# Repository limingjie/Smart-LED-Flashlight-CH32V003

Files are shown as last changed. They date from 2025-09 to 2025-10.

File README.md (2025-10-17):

# Smart LED Flashlight - CH32V003

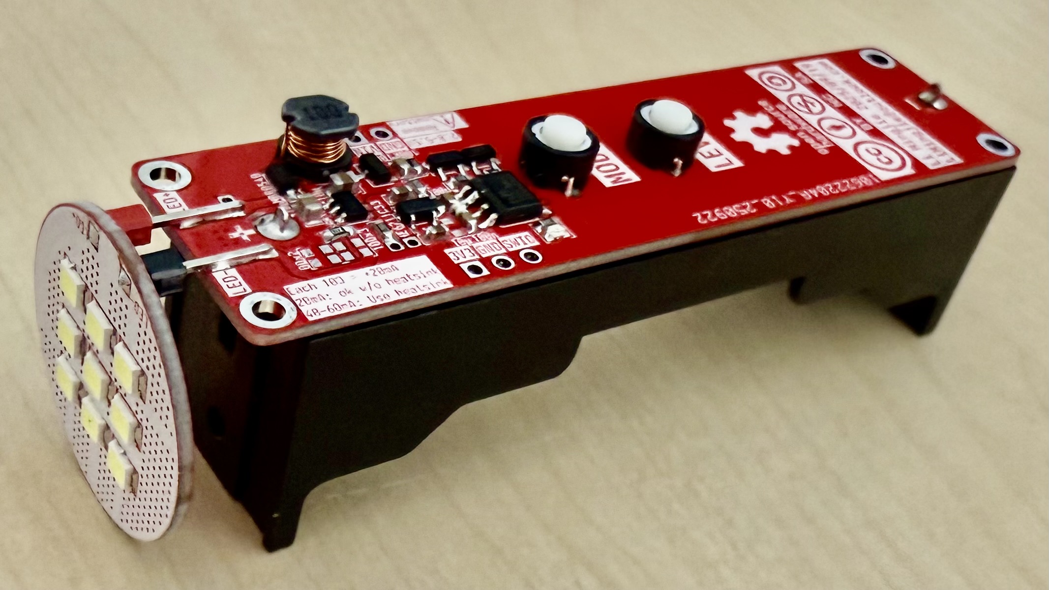
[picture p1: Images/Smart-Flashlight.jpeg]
Flashlight


**Smart LED Flashlight - CH32V003** is an open-source, compact, and energy-efficient flashlight solution based on the CH32V003 RISC-V microcontroller and SGM3732 LED driver.

It features multiple adjustable brightness lighting modes (Steady, Breathing, Blinking, SOS), battery monitoring, and zero standby current via a soft latching power circuit.

Designed for DIY enthusiasts, emergency kits, portable lighting, and educational projects.

- Low-cost, minimal component count
- USB or battery powered (3.0V–5.5V)
- Up to 10 LEDs in series
- Advanced features: PWM dimming, SOS mode, battery protection
- Open source hardware and firmware

---

- [Smart LED Flashlight - CH32V003](#smart-led-flashlight---ch32v003)
  - [Circuit on Breadboard](#circuit-on-breadboard)
  - [Schematic](#schematic)
  - [Features](#features)
  - [Components](#components)
    - [MCU - CH32V003](#mcu---ch32v003)
      - [Clock Selection](#clock-selection)
      - [Battery Monitoring](#battery-monitoring)
    - [LED Driver - SGM3732](#led-driver---sgm3732)
    - [Soft Latching Power Circuit](#soft-latching-power-circuit)
    - [LDO - ME6211](#ldo---me6211)
  - [Minimized ch32fun Library](#minimized-ch32fun-library)
  - [References](#references)
  - [License](#license)

## Circuit on Breadboard

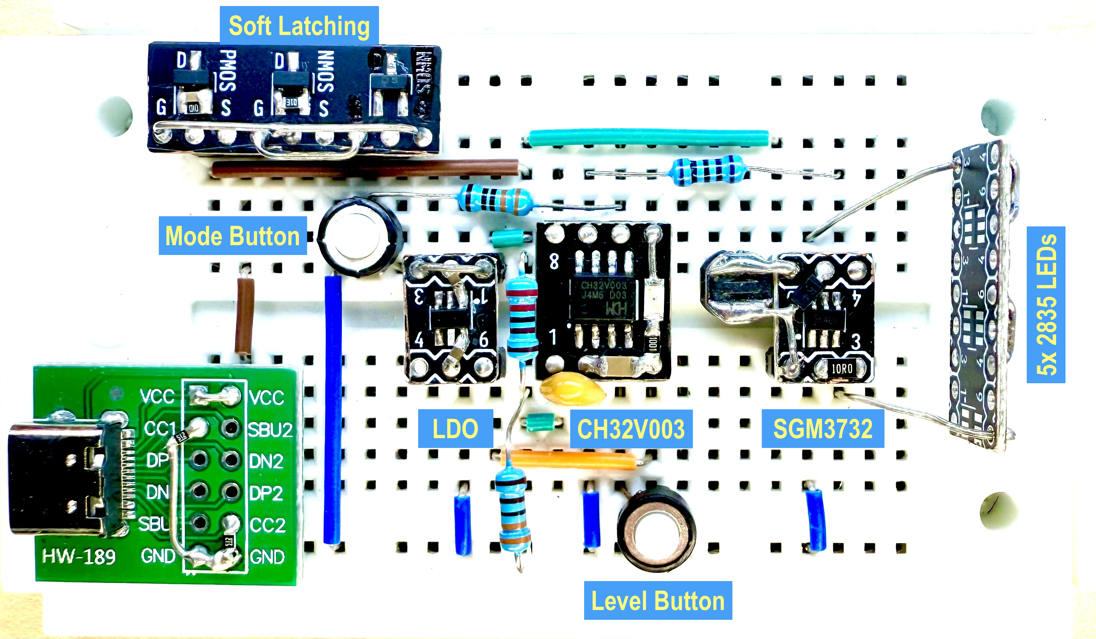
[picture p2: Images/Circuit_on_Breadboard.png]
Circuit on Breadboard


## Schematic

Schematic

## Features

- Low-cost
- PWM-controlled adjustable brightness
- Supports up to 10 LEDs in series
- Operates from `3.0V` to `5.5V` (suitable for single cell lithium battery)
- Soft latching power circuit for zero standby current
- Automatic power monitoring and low-voltage lockout to prevent battery drain
- 4 Modes - `Steady`, `Breathing`, `Blinking`, and `SOS`.
  - Click/Double click `Mode` button to switch to previous/next mode.
  - Hold `Mode` button anytime to directly switch to `SOS` mode.
- 8 Levels
  - Click/Double click `Level` button to increase/decrease.
  - Hold `Level` button to switch between min and max.

## Components

### MCU - CH32V003

The CH32V003 is a low-cost, high-performance 32-bit RISC-V microcontroller from WCH. It features a compact design, low power consumption, and a rich set of peripherals, making it ideal for embedded applications and cost-sensitive projects. The CH32V003 supports various interfaces such as UART, SPI, I2C, and PWM, and is well-suited for controlling LED drivers and other hardware components.

- [CH32V003 Datasheet V1.7](./Documents/CH32V003%20Datasheet%20-%20V1.7.PDF)
- [CH32V003 Reference Manual V1.7](./Documents/CH32V003%20Reference%20Manual%20-%20V1.7.PDF)

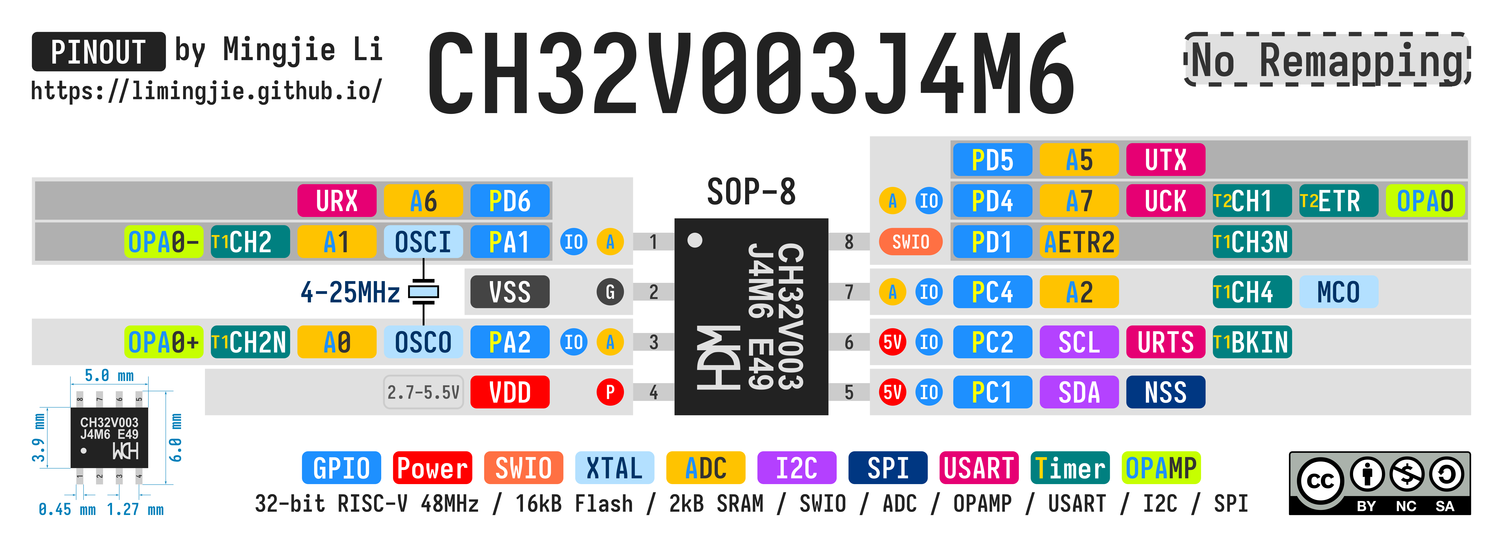
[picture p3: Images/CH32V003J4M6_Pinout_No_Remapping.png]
CH32V003 Pinout


[Link to More CH32V003 Pinout charts](https://github.com/limingjie/WCH-MCU-Pinouts/tree/main/MCU/CH32V)

#### Clock Selection

With a `1.5MHz` clock (`1/16` of the internal `24MHz` high-speed clock), the CH32V003 draws around `1.53mA` (the power LED draws around `1.35mA`). With clocks lower than `1.5MHz`, CH32V003 does not seem to work properly with ADC enabled and may brick the chip. If this happens, try the unbrick command (`minichlink -u`) or flash a firmware with a higher clock; note that it may require more than 10 attempts. The chip is quite robust, but recovering it may require patience!

#### Battery Monitoring

When using a lithium battery as the power supply, and considering the cutoff voltages of the CH32V003 and SGM3732, the lockout voltage is set at `3.0V` if detected 3 times.

- CH32V003: `2.8V`-`5.5V` (With ADC).
- SGM3732: `2.7V`-`5.5V`.

Since the power supply can drop below `3.3V`, directly using `3.3V` as the ADC reference would lead to inaccurate results. Fortunately, the CH32V003 provides an internal voltage reference (`1.2V` on analog channel 8), which allows for accurate ADC measurements with an error within `±1%`.

$$
\begin{align}
\text{V}_\text{Reference} &= \text{V}_\text{DD} \times \frac{\text{ADC}_{\text{Reference}}}{1023}
\Longrightarrow \text{V}_\text{DD} = \frac{\text{V}_\text{Reference}}{\frac{\text{ADC}_{\text{Reference}}}{1023}} \\
\text{V}_\text{Battery} &= \text{V}_\text{DD} \times \frac{\text{ADC}_{\text{Battery}}}{1023} \\
&= \frac{\text{V}_\text{Reference}}{\frac{\text{ADC}_{\text{Reference}}}{1023}} \times \frac{\text{ADC}_{\text{Battery}}}{1023} \\
&= \text{V}_\text{Reference} \times \frac{\text{ADC}_{\text{Battery}}}{\text{ADC}_\text{Reference}}\\
&=  1.2\ \text{V} \times \frac{\text{ADC}_{\text{Battery}}}{\text{ADC}_\text{Reference}}
\end{align}
$$

### LED Driver - SGM3732

The [SGM3732](https://www.sg-micro.com/product/SGM3732) is a high-efficiency constant current LED driver with a 1.1MHz PWM boost converter, optimized for compact designs using small components. It can drive up to 10 LEDs in series (up to 38V output) or deliver up to 260mA with 3 LEDs per string, while maintaining high conversion efficiency. LED current is programmable via a digital PWM dimming interface (2kHz–60kHz). The device features very low shutdown current and includes protections such as over-voltage, cycle-by-cycle input current limit, and thermal shutdown. The SGM3732 is available in a TSOT-23-6 package and operates from -40℃ to +85℃.

- [SGM3732 Datasheet Rev A4](./Documents/SGM3732%20Datasheet%20-%20Rev%20A4.pdf)
- [SGM3732 Datasheet Rev A3](./Documents/SGM3732%20Datasheet%20-%20Rev%20A3.pdf) – The older version includes circuit design and component selection guidance.

### Soft Latching Power Circuit

Refer to the [CH32V003 Soft Latching Power Circuits](https://github.com/limingjie/CH32V003-Soft-Latching-Power-Circuits) project.

### LDO - ME6211

The CH32V003 operates from `2.7V` to `5.5V`, but shows noticeable current fluctuations when powered directly from USB. Using an LDO stabilizes the MCU’s power supply and reduces current consumption by a few milliamps.

When the input voltage drops under `3.3V`, LDO stops regulate, the output voltage is $\text{V}_\text{In} - \text{V}_\text{Dropout}$. The dropout voltage is `~2.6mV` ($\text{V}_\text{In}$ = `~3.3V`) to `5mV` ($\text{V}_\text{In}$ = `2.85V`) when the power consumption is `~3mA`.

- [ME6211 Datasheet - V24](./Documents/ME6211%20Datasheet%20-%20V26.pdf)

## Minimized ch32fun Library

- **`ch32fun.mk`** - Some modifications to accommodate library and tool paths.
  - The `LDFLAGS` path change is for locating the `ch32fun/libgcc.a`.

    ```diff
    <     LDFLAGS+=-L$(CH32FUN)/../misc -lgcc
    ---
    >     LDFLAGS+=-L$(CH32FUN) -lgcc
    ```

    - Otherwise, the compiler would use the default libgcc and throw an incompatible linking error:

      ```text
      .../riscv64-unknown-elf/bin/ld:
      .../riscv-gnu-toolchain/main/lib/gcc/riscv64-unknown-elf/15.1.0/libgcc.a(div.o):
      ABI is incompatible with that of the selected emulation:
      target emulation `elf64-littleriscv' does not match `elf32-littleriscv'
      ```

  - The other two changes are for `minichlink`:

    ```diff
    33c33
    < MINICHLINK?=$(CH32FUN)/../minichlink
    ---
    > MINICHLINK?=$(CH32FUN)
    51c51
    <     LDFLAGS+=-L$(CH32FUN)/../misc -lgcc
    ---
    >     LDFLAGS+=-L$(CH32FUN) -lgcc
    350c350
    <     make -C $(MINICHLINK) all
    ---
    >     # make -C $(MINICHLINK) all
    ```

- **`ch32fun.c`**
  - Changed line `1728` for `6MHz` HCLK, resulting in lower power consumption (<`2.6mA`).

    ```c
    1720: #elif defined(FUNCONF_USE_HSI) && FUNCONF_USE_HSI
    1721: #if defined(CH32V30x) || defined(CH32V20x) || defined(CH32V10x)
    1722:     EXTEN->EXTEN_CTR |= EXTEN_PLL_HSI_PRE;
    1723: #endif
    1724: #if defined(FUNCONF_USE_PLL) && FUNCONF_USE_PLL
    1725:     RCC->CFGR0 = BASE_CFGR0;
    1726:     RCC->CTLR  = BASE_CTLR | RCC_HSION | RCC_PLLON; // Use HSI, enable PLL.
    1727: #else
    1728:     RCC->CFGR0 = RCC_HPRE_DIV4;                    // HCLK = SYSCLK / 4
    1729:     RCC->CTLR  = BASE_CTLR | RCC_HSION;             // Use HSI only.
    1730: #endif
    ```

  - Set ADC sampling time to `241` cycles for better accuracy.

    ```c
    1808: // set sampling time for all channels to 0b111 (241 cycles).
    1809: ADC1->SAMPTR2 = (ADC_SMP0<<(3*0)) | (ADC_SMP0<<(3*1)) | (ADC_SMP0<<(3*2)) | (ADC_SMP0<<(3*3)) | (ADC_SMP0<<  (3*4)) | (ADC_SMP0<<(3*5)) | (ADC_SMP0<<(3*6)) | (ADC_SMP0<<(3*7)) | (ADC_SMP0<<(3*8)) | (ADC_SMP0<<(3*9));
    1810: ADC1->SAMPTR1 = (ADC_SMP0<<(3*0)) | (ADC_SMP0<<(3*1)) | (ADC_SMP0<<(3*2)) | (ADC_SMP0<<(3*3)) | (ADC_SMP0<<  (3*4)) | (ADC_SMP0<<(3*5));
    ```

## References

- [Andrew Levido: Soft Latching Power Circuits](https://circuitcellar.com/resources/quickbits/soft-latching-power-circuits/)
- [CNLohr: ch32fun](https://github.com/cnlohr/ch32fun)
- [A Guide to Debouncing](https://my.eng.utah.edu/~cs5780/debouncing.pdf)
- [The simplest button debounce solution](https://www.e-tinkers.com/2021/05/the-simplest-button-debounce-solution/)
- [Museum of the Game - Let's design some POKEY replacements](https://forums.arcade-museum.com/threads/lets-design-some-pokey-replacements.515774/post-4623716)

## License

CC by-nc-sa

This work is licensed under a [Creative Commons Attribution-NonCommercial-ShareAlike 4.0 International License (CC BY-NC-SA 4.0)](https://creativecommons.org/licenses/by-nc-sa/4.0/).

**You are free to:**

- **Share** — copy and redistribute the material in any medium or format
- **Adapt** — remix, transform, and build upon the material

The licensor cannot revoke these freedoms as long as you follow the license terms.

**Under the following terms:**

- **Attribution** - You must give appropriate credit, provide a link to the license, and indicate if changes were made. You may do so in any reasonable manner, but not in any way that suggests the licensor endorses you or your use.
- **NonCommercial** - You may not use the material for commercial purposes.
- **ShareAlike** - If you remix, transform, or build upon the material, you must distribute your contributions under the same license as the original.
- **No additional restrictions** — You may not apply legal terms or technological measures that legally restrict others from doing anything the license permits.

**Notices:**

You do not have to comply with the license for elements of the material in the public domain or where your use is permitted by an applicable exception or limitation.

No warranties are given. The license may not give you all of the permissions necessary for your intended use. For example, other rights such as publicity, privacy, or moral rights may limit how you use the material.

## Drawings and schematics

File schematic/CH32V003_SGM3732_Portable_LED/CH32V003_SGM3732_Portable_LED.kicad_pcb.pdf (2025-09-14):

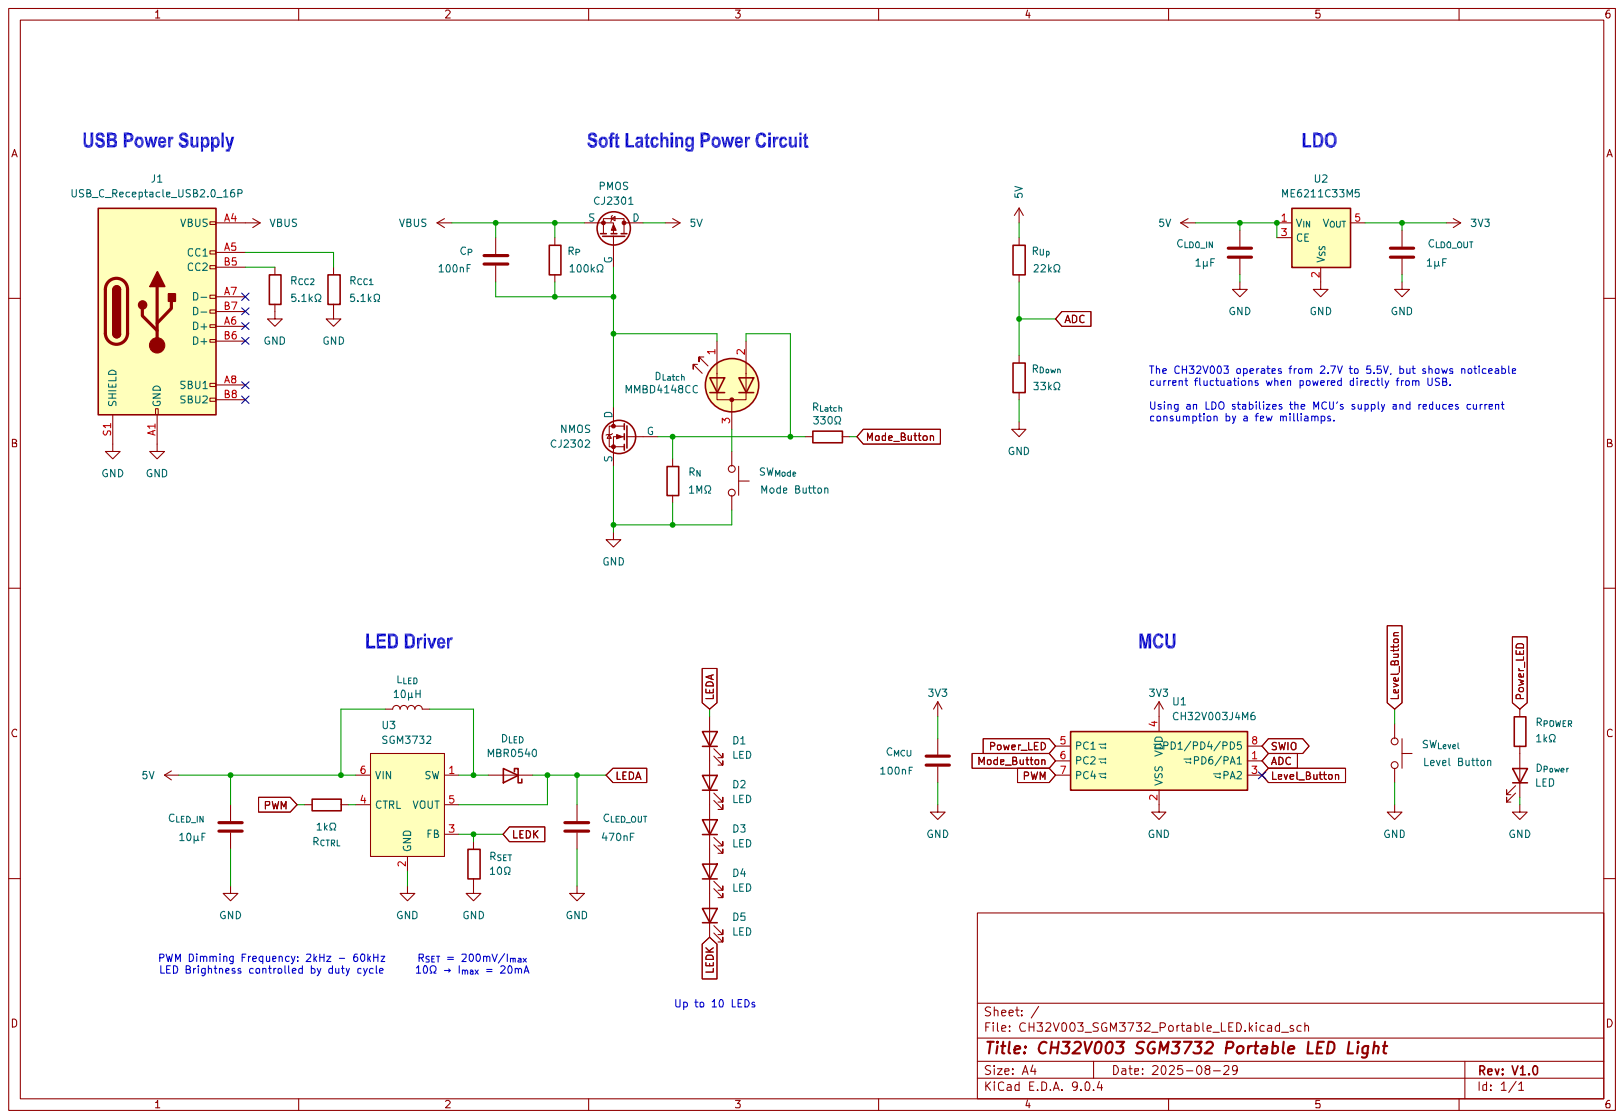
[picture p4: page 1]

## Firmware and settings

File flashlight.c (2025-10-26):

/*
 * Smart LED Flashlight - CH32V003
 *
 * Aug 2025 by Li Mingjie
 *  - Email:  limingjie@outlook.com
 *  - GitHub: https://github.com/limingjie/
 */

#include <stdio.h>
#include <stdlib.h>
#include "ch32fun.h"
#include "button.h"

#define PIN_POWER_LED     PC1       // Power LED pin
#define PIN_LATCH         PC2       // Latch pin
#define PIN_MODE_BUTTON   PC2       // Mode button pin, same as latch pin
#define PIN_LEVEL_BUTTON  PA2       // Set button pin
#define PIN_PWM           PC4       // PWM output pin
#define PIN_POWER_MONITOR PD6       // Power monitoring pin
#define ADC_POWER_MONITOR ANALOG_6  // Power monitoring ADC channel A6 (PD6)

#define POWER_MONITORING_CYCLES     1000  // Every 5 seconds - button_debounce() = 5ms
#define POWER_VOLT_DIV_R_UP         2     // 22k or 10k   | 2:3 voltage divider
#define POWER_VOLT_DIV_R_DOWN       3     // 33k or 15k   | 5.5V / 5 x 3 = 3.3V
#define POWER_LOW_VOLT_THRESHOLD_MV 3000  // 3.0V
#define POWER_LOW_COUNT_THRESHOLD   3     // 3 times

#define PWM_FREQUENCY              ((uint32_t)60 * 1000)                        // 60kHz
#define PWM_CLOCKS_FULL_DUTY_CYCLE (FUNCONF_SYSTEM_CORE_CLOCK / PWM_FREQUENCY)  // 100% duty cycle
#define PWM_CLOCKS_ZERO_DUTY_CYCLE 0                                            // 0% duty cycle
#define PWM_SEQUENCE_ON            1
#define PWM_SEQUENCE_OFF           0
#define PWM_SEQUENCE_INCREASE      1
#define PWM_SEQUENCE_DECREASE      0

#define MORSE_CODE_DIT_DURATION_MS 150  // 100ms

// #define printf(...) (void)0  // Disable printf to save flash

enum light_modes
{
    MODE_STEADY,
    MODE_BREATHING,
    MODE_BLINKING,
    MODE_SOS,
    MODE_OFF
};

const char* mode_names[] = {"MODE_STEADY", "MODE_BREATHING", "MODE_BLINKING", "MODE_SOS"};

uint8_t  current_mode           = 0;     // 5 modes: brightness, blink, dimming, sos, off
uint8_t  current_level          = 0;     // 0-7 levels of brightness, blink speed, dimming speed.
uint16_t current_pwm_duty_cycle = 0;     // Lights off
uint32_t pwm_update_interval_ms = 1000;  // systick interval in ms, set before initialize systick.
uint8_t  pwm_sequence           = 0;     // 0 - off / decrease; 1 - on / increase; 0-31 - sos sequence

void systick_init(void)
{
    SysTick->CTLR = 0;
    NVIC_EnableIRQ(SysTicK_IRQn);
    SysTick->CMP  = FUNCONF_SYSTEM_CORE_CLOCK / 1000 * pwm_update_interval_ms;
    SysTick->CNT  = 0;
    SysTick->CTLR = SYSTICK_CTLR_STE | SYSTICK_CTLR_STIE | SYSTICK_CTLR_STCLK;
}

// Gamma brightness lookup table <https://victornpb.github.io/gamma-table-generator>
// gamma = 2.00 steps = 100 range = 0-1023
const uint16_t gamma_lookup_table[100] = {
    0,   0,   0,   1,   2,   3,   4,   5,   7,   8,   10,  13,  15,  18,  20,  23,  27,  30,  34,   38,
    42,  46,  51,  55,  60,  65,  71,  76,  82,  88,  94,  100, 107, 114, 121, 128, 135, 143, 151,  159,
    167, 175, 184, 193, 202, 211, 221, 231, 240, 251, 261, 271, 282, 293, 304, 316, 327, 339, 351,  363,
    376, 388, 401, 414, 428, 441, 455, 469, 483, 497, 511, 526, 541, 556, 572, 587, 603, 619, 635,  651,
    668, 685, 702, 719, 736, 754, 772, 790, 808, 827, 845, 864, 883, 903, 922, 942, 962, 982, 1002, 1023,
};

void disable_systick(void)
{
    NVIC_DisableIRQ(SysTicK_IRQn);
}

void SysTick_Handler(void) __attribute__((interrupt));
void SysTick_Handler(void)
{
    SysTick->CMP += FUNCONF_SYSTEM_CORE_CLOCK / 1000 * pwm_update_interval_ms;
    SysTick->SR = 0;

    // process mode and level changes
    switch (current_mode)
    {
        case MODE_BREATHING:
            TIM1->CH4CVR = PWM_CLOCKS_FULL_DUTY_CYCLE * gamma_lookup_table[current_pwm_duty_cycle] / 1023;
            (pwm_sequence == PWM_SEQUENCE_INCREASE) ? current_pwm_duty_cycle++ : current_pwm_duty_cycle--;
            if (current_pwm_duty_cycle >= 100 || current_pwm_duty_cycle <= 0)
            {
                pwm_sequence = !pwm_sequence;
            }
            break;
        case MODE_BLINKING:
            TIM1->CH4CVR = (pwm_sequence == PWM_SEQUENCE_ON) ? PWM_CLOCKS_FULL_DUTY_CYCLE : PWM_CLOCKS_ZERO_DUTY_CYCLE;
            pwm_sequence = !pwm_sequence;
            break;
        case MODE_SOS:
            // From Wikipedia:
            // > The duration of a dah is three times the duration of a dit. Each dit or dah within an encoded character
            // > is followed by a period of signal absence, called a space, equal to the dit duration.
            // SOS Morse Code is the following sequence under a fixed systick.
            //   Morse Code - . . . --- --- --- . . . <-Wait->  | SOS   Time   = 0.15s x 24 = 3.6s
            //       Binary - 10101011101110111010101000000000  | Pause Time   = 0.15s x  8 = 1.2s
            //                |----+----|----+----|----+----|-  | Total Time   = 0.15s x 32 = 4.8s
            //     Sequence - 0    5   10   15   20   25   30   | No. Sequence = 32
            //           On - 0 2 4 678 012 456 8 0 2           | On  Sequence = 15
            //          Off -  1 3 5   9   3   7 9 1 345678901  | Off Sequence = 17
            TIM1->CH4CVR = (pwm_sequence >= 23 ||
                            ((pwm_sequence & 0x1) && pwm_sequence != 7 && pwm_sequence != 11 && pwm_sequence != 15))
                               ? PWM_CLOCKS_ZERO_DUTY_CYCLE
                               : PWM_CLOCKS_FULL_DUTY_CYCLE;

            pwm_update_interval_ms = MORSE_CODE_DIT_DURATION_MS;

            pwm_sequence++;
            pwm_sequence &= 0x1F;  // pwm_sequence %= 32;
            break;
    }
}

void tim1_pwm_init(void)
{
    // Enable GPIOC and TIM1
    RCC->APB2PCENR |= RCC_APB2Periph_GPIOC | RCC_APB2Periph_TIM1;

    // PC4 is T1CH4, 10MHz Output alt func, push-pull
    GPIOC->CFGLR &= ~(0xf << (4 * 4));
    GPIOC->CFGLR |= (GPIO_Speed_10MHz | GPIO_CNF_OUT_PP_AF) << (4 * 4);

    // Reset TIM1 to init all regs
    RCC->APB2PRSTR |= RCC_APB2Periph_TIM1;
    RCC->APB2PRSTR &= ~RCC_APB2Periph_TIM1;

    // Prescaler
    TIM1->PSC = 0x0000;

    // Auto Reload - sets period
    TIM1->ATRLR = PWM_CLOCKS_FULL_DUTY_CYCLE - 1;

    // Reload immediately
    TIM1->SWEVGR |= TIM_UG;

    // Enable CH4 output, positive pol
    TIM1->CCER |= TIM_CC4E | TIM_CC4NP;

    // CH2 Mode is output, PWM1 (CC1S = 00, OC1M = 110)
    TIM1->CHCTLR2 |= TIM_OC4M_2 | TIM_OC4M_1;

    // Set the Capture Compare Register value to 0% initially
    TIM1->CH4CVR = PWM_CLOCKS_ZERO_DUTY_CYCLE;

    // Enable TIM1 outputs
    TIM1->BDTR |= TIM_MOE;

    // Enable TIM1
    TIM1->CTLR1 |= TIM_CEN;
}

void blink_power_led(uint8_t times)
{
    for (uint8_t i = 0; i < times; i++)
    {
        funDigitalWrite(PIN_POWER_LED, FUN_HIGH);  // Turn on LED
        Delay_Ms(100);
        funDigitalWrite(PIN_POWER_LED, FUN_LOW);  // Turn off LED
        Delay_Ms(100);
    }
}

void power_monitor(void)
{
    static uint8_t power_low_count = 0;
    uint16_t       adc_ref         = 0;  // Internal reference 1.2V
    uint16_t       adc_mon         = 0;
    uint32_t       adc_volt_mv;
    uint32_t       power_volt_mv;

    // Average 8 samples for better stability
    for (uint8_t i = 0; i < 8; i++)
    {
        adc_ref += funAnalogRead(ANALOG_8);           // Internal reference 1.2V
        adc_mon += funAnalogRead(ADC_POWER_MONITOR);  // A6 (PD6)
    }
    adc_ref /= 8;
    adc_mon /= 8;

    adc_volt_mv   = (uint32_t)adc_mon * 1200 / adc_ref;
    power_volt_mv = adc_volt_mv * (POWER_VOLT_DIV_R_UP + POWER_VOLT_DIV_R_DOWN) / POWER_VOLT_DIV_R_DOWN;

    printf("Vref: 1.2 V (%d) | Vadc: %ld mV (%d) | Vpower: %ld mV\n", adc_ref, adc_volt_mv, adc_mon, power_volt_mv);

    if (power_volt_mv < POWER_LOW_VOLT_THRESHOLD_MV)
    {
        if (++power_low_count >= POWER_LOW_COUNT_THRESHOLD)
        {
            printf("Battery too low! Powering off...\n");
            blink_power_led(10);
            funDigitalWrite(PIN_LATCH, FUN_LOW);  // Input pull-down
            // For debugging purpose only, code should not reach here if correctly shutdown.
            power_low_count = 0;
        }
    }
    else
    {
        power_low_count = 0;
    }
}

void update_led(void)
{
    printf("Change to %s, level %d\n", mode_names[current_mode], current_level);

    disable_systick();

    switch (current_mode)
    {
        case MODE_STEADY:
            TIM1->CH4CVR = (PWM_CLOCKS_FULL_DUTY_CYCLE * (8 - current_level)) >> 3;  // 12.5, 25%, 37.5%, ..., 100%
            break;
        case MODE_BREATHING:
            pwm_sequence           = PWM_SEQUENCE_DECREASE;     // Starts by decreasing brightness
            pwm_update_interval_ms = (current_level + 1) << 1;  // 2ms, 4ms, 6ms, ..., 16ms
            current_pwm_duty_cycle = 100;                       // 100% duty cycle
            systick_init();
            break;
        case MODE_BLINKING:
            pwm_sequence           = PWM_SEQUENCE_ON;
            pwm_update_interval_ms = (current_level + 3) << 5;  // 96ms, 128ms, 160ms, ..., 320ms
            systick_init();
            break;
        case MODE_SOS:
            pwm_sequence           = 0;                           // Reset sequence
            TIM1->CH4CVR           = PWM_CLOCKS_ZERO_DUTY_CYCLE;  // Pause before SOS
            pwm_update_interval_ms = MORSE_CODE_DIT_DURATION_MS;
            systick_init();
            break;
        case MODE_OFF:
            TIM1->CH4CVR = PWM_CLOCKS_ZERO_DUTY_CYCLE;
            break;
    }
}

int main(void)
{
    SystemInit();
    Delay_Ms(50);

    funGpioInitAll();

    // Power on latch by input pull-up
    funPinMode(PIN_LATCH, GPIO_CFGLR_IN_PUPD);
    funDigitalWrite(PIN_LATCH, FUN_HIGH);

    // Init LED pin
    funPinMode(PIN_POWER_LED, GPIO_Speed_10MHz | GPIO_CNF_OUT_PP);
    funDigitalWrite(PIN_POWER_LED, FUN_HIGH);

    // Init ADC for battery voltage monitoring
    funAnalogInit();
    funPinMode(PIN_POWER_MONITOR, GPIO_CFGLR_IN_ANALOG);

    // Init TIM1 for PWM
    tim1_pwm_init();
    // TIM1->CH4CVR = PWM_CLOCKS_FULL_DUTY_CYCLE;  // Starts with MODE_STEADY - 100% brightness
    update_led();

    button_t mode_button;
    init_button(&mode_button, PIN_MODE_BUTTON);
    button_t level_button;
    init_button(&level_button, PIN_LEVEL_BUTTON);

    uint16_t power_monitoring_cycles = 0;
    while (1)
    {
        switch (get_button_event(&mode_button))
        {
            case BUTTON_HOLD:  // Enter SOS mode directly
                if (current_mode != MODE_SOS)
                {
                    current_mode = MODE_SOS;
                    update_led();
                }
                break;
            case BUTTON_RELEASED:  // Light mode +
                // printf("Mode button released.\n");
                // Move to next mode
                current_mode++;
                if (current_mode == MODE_OFF)
                {
                    // printf("Powering off...\n");
                    funDigitalWrite(PIN_LATCH, FUN_LOW);  // Input pull-down

                    // These following lines are for debugging purpose only, code should not reach here if correctly
                    // shutdown. However, if the MCU is powered by WCH-LinkE, the code will keep running. And, the
                    // button processing logic would detect the power off pull down as a button down, then there would
                    // be endless BUTTON_HOLD events.
                    Delay_Ms(100);
                    funDigitalWrite(PIN_LATCH, FUN_HIGH);  // Input pull-up
                    current_mode  = MODE_STEADY;
                    current_level = 0;
                    update_led();
                    break;
                }

                current_level = 0;  // Reset level to max
                update_led();
                break;
            case BUTTON_DOUBLE_PRESS_RELEASED:  // Light mode -
            case BUTTON_TRIPLE_PRESS_RELEASED:
            case BUTTON_MORE_PRESS_RELEASED:
                if (current_mode > MODE_STEADY)
                {
                    current_mode--;
                    current_level = 0;  // Reset level to max
                    update_led();
                }
                break;
        }

        switch (get_button_event(&level_button))
        {
            case BUTTON_RELEASED:  // Light level +
                // printf("Set button released.\n");
                if (current_mode != MODE_SOS)  // Do not interfere with SOS mode
                {
                    current_level++;
                    current_level %= 8;  // 0 - 7
                    update_led();
                }
                break;
            case BUTTON_DOUBLE_PRESS_RELEASED:  // Light level -
            case BUTTON_TRIPLE_PRESS_RELEASED:
            case BUTTON_MORE_PRESS_RELEASED:
                // printf("Set button double press released.\n");
                if (current_mode != MODE_SOS)  // Do not interfere with SOS mode
                {
                    if (current_level > 0)
                    {
                        current_level--;
                    }
                    else
                    {
                        current_level = 7;
                    }
                    update_led();
                }
                break;
            case BUTTON_HOLD:  // Change light level to min or max
                // printf("Set button hold.\n");
                if (current_mode != MODE_SOS)  // Do not interfere with SOS mode
                {
                    current_level = (current_level & 0x4) ? 0 : 7;  // 0/1/2/3 -> 7; 4/5/6/7 -> 0
                    update_led();
                }
                break;
        }

        if (current_mode != MODE_SOS)  // In an SOS, do not check power to avoid interference
        {
            if (++power_monitoring_cycles >= POWER_MONITORING_CYCLES)
            {
                power_monitor();
                power_monitoring_cycles = 0;
            }
        }

        debounce_delay();
    }
}

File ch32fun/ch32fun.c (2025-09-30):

// Mixture of embedlibc, and ch32v00x_startup.c
// Use with newlib headers.
// Mixture of weblibc, mini-printf and ???
/* This file contains the following functions:

// libc (via musl) mixture and miniprintf

int printf( const char* format, ... )
int vprintf(const char* format, va_list args)
int snprintf( char * buffer, unsigned int buffer_len, const char* format, ... )
int sprintf( char * buffer, const char * format, ... )
size_t wcrtomb(char *restrict s, wchar_t wc, mbstate_t *restrict st)
int wctomb(char *s, wchar_t wc)
size_t strlen(const char *s)
size_t strnlen(const char *s, size_t n)
void *memset(void *dest, int c, size_t n)
char *strcpy(char *d, const char *s)
char *strncpy(char *d, const char *s, size_t n)
int strcmp(const char *l, const char *r)
int strncmp(const char *_l, const char *_r, size_t n)
static char *twobyte_strstr(const unsigned char *h, const unsigned char *n)
static char *threebyte_strstr(const unsigned char *h, const unsigned char *n)
static char *fourbyte_strstr(const unsigned char *h, const unsigned char *n)
static char *twoway_strstr(const unsigned char *h, const unsigned char *n)
char *strstr(const char *h, const char *n)
char *strchr(const char *s, int c)
void *__memrchr(const void *m, int c, size_t n)
char *strrchr(const char *s, int c)
void *memcpy(void *dest, const void *src, size_t n)
int memcmp(const void *vl, const void *vr, size_t n)
void *memmove(void *dest, const void *src, size_t n)
void *memchr(const void *src, int c, size_t n)
int puts(const char *s)
int mini_itoa(long value, unsigned int radix, int uppercase, int unsig,
	 char *buffer)
int mini_vsnprintf(char *buffer, unsigned int buffer_len, const char *fmt, va_list va)
int mini_vpprintf(int (*puts)(char* s, int len, void* buf), void* buf, const char *fmt, va_list va)
int mini_snprintf(char* buffer, unsigned int buffer_len, const char *fmt, ...)
int mini_pprintf(int (*puts)(char*s, int len, void* buf), void* buf, const char *fmt, ...)

// IRQ Handling Code
void DefaultIRQHandler( void )
void NMI_RCC_CSS_IRQHandler( void )

// Startup Code
void InterruptVectorDefault( void )
void handle_reset( void )

// Configuration-specific I/O

#if defined( FUNCONF_USE_UARTPRINTF ) && FUNCONF_USE_UARTPRINTF
void SetupUART( int uartBRR )
int _write(int fd, const char *buf, int size)
int putchar(int c)
#endif

#if defined( FUNCONF_USE_DEBUGPRINTF ) && FUNCONF_USE_DEBUGPRINTF
void handle_debug_input( int numbytes, uint8_t * data ) // You can override this!
void poll_input( void )
int _write(int fd, const char *buf, int size)
int putchar(int c)
void SetupDebugPrintf( void )
void WaitForDebuggerToAttach()
#endif

#if (defined( FUNCONF_USE_DEBUGPRINTF ) && !FUNCONF_USE_DEBUGPRINTF) && \
	(defined( FUNCONF_USE_UARTPRINTF ) && !FUNCONF_USE_UARTPRINTF) && \
	(defined( FUNCONF_NULL_PRINTF ) && FUNCONF_NULL_PRINTF)

int _write(int fd, const char *buf, int size)
int putchar(int c)
#endif

void DelaySysTick( uint32_t n )
void SystemInit( void )

#ifdef CPLUSPLUS
extern void __cxa_pure_virtual()
void __libc_init_array(void)
#endif

*/

// We pre-define these, because if the user is (for some awful reason) using gcc-riscv64-linux-gnu with newlib, it will fail to compile if it janks up the stdio/string functions.
#define _SSP_STRING_H_
#define _SSP_STDIO_H_

#include <stdio.h>
#include <string.h>
#include <stdarg.h>
#include <limits.h>
#include <stdint.h>
#include <ch32fun.h>

#define WEAK __attribute__((weak))

WEAK int errno;

static int __puts_uart( char *s, int len, void *buf )
{
	(void)buf;

	_write( 0, s, len );
	return len;
}

WEAK int printf( const char* format, ... )
{
	va_list args;
	va_start( args, format );
	int ret_status = mini_vpprintf(__puts_uart, 0, format, args);
	va_end( args );
	return ret_status;
}

WEAK int vprintf(const char* format, va_list args)
{
	return mini_vpprintf(__puts_uart, 0, format, args);
}

WEAK int snprintf( char * buffer, unsigned int buffer_len, const char* format, ... )
{
	va_list args;
	va_start( args, format );
	int ret = mini_vsnprintf( buffer, buffer_len, format, args );
	va_end( args );
	return ret;
}

WEAK int sprintf( char * buffer, const char * format, ... )
{
	va_list args;
	va_start( args, format );
	int ret = mini_vsnprintf( buffer, INT_MAX, format, args );
	va_end( args );
	return ret;
}

/* Some stuff from MUSL


----------------------------------------------------------------------
Copyright © 2005-2020 Rich Felker, et al.

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
THE SOFTWARE IS PROVIDED "AS IS", WITHOUT WARRANTY OF ANY KIND,
EXPRESS OR IMPLIED, INCLUDING BUT NOT LIMITED TO THE WARRANTIES OF
MERCHANTABILITY, FITNESS FOR A PARTICULAR PURPOSE AND NONINFRINGEMENT.
IN NO EVENT SHALL THE AUTHORS OR COPYRIGHT HOLDERS BE LIABLE FOR ANY
CLAIM, DAMAGES OR OTHER LIABILITY, WHETHER IN AN ACTION OF CONTRACT,
TORT OR OTHERWISE, ARISING FROM, OUT OF OR IN CONNECTION WITH THE
SOFTWARE OR THE USE OR OTHER DEALINGS IN THE SOFTWARE.
----------------------------------------------------------------------

*/

/*
 * mbstate_t is an opaque object to keep conversion state, during multibyte
 * stream conversions.  The content must not be referenced by user programs.
 */

#define CURRENT_UTF8 0
#define IS_CODEUNIT(c) ((unsigned)(c)-0xdf80 < 0x80)
#define MB_CUR_MAX (CURRENT_UTF8 ? 4 : 1)

typedef void * mbstate_t;

#ifdef UNICODE
WEAK size_t wcrtomb(char *restrict s, wchar_t wc, mbstate_t *restrict st)
{
	if (!s) return 1;
	if ((unsigned)wc < 0x80) {
		*s = wc;
		return 1;
	} else if (MB_CUR_MAX == 1) {
		if (!IS_CODEUNIT(wc)) {
			errno = 0x02; // EILSEQ
			return -1;
		}
		*s = wc;
		return 1;
	} else if ((unsigned)wc < 0x800) {
		*s++ = 0xc0 | (wc>>6);
		*s = 0x80 | (wc&0x3f);
		return 2;
	} else if ((unsigned)wc < 0xd800 || (unsigned)wc-0xe000 < 0x2000) {
		*s++ = 0xe0 | (wc>>12);
		*s++ = 0x80 | ((wc>>6)&0x3f);
		*s = 0x80 | (wc&0x3f);
		return 3;
	} else if ((unsigned)wc-0x10000 < 0x100000) {
		*s++ = 0xf0 | (wc>>18);
		*s++ = 0x80 | ((wc>>12)&0x3f);
		*s++ = 0x80 | ((wc>>6)&0x3f);
		*s = 0x80 | (wc&0x3f);
		return 4;
	}
	errno = 0x02;//EILSEQ;
	return -1;
}
WEAK int wctomb(char *s, wchar_t wc)
{
	if (!s) return 0;
	return wcrtomb(s, wc, 0);
}
#endif
WEAK size_t strlen(const char *s)
{
	const char *a = s;
	for (; *s; s++);
	return s-a;
}
WEAK size_t strnlen(const char *s, size_t n) { const char *p = memchr(s, 0, n); return p ? (size_t)(p-s) : n;}
WEAK void *memset(void *dest, int c, size_t n) { unsigned char *s = dest; for (; n; n--, s++) *s = c; return dest; }
WEAK char *strcpy(char *d, const char *s)
{
	char *d0=d;
	for (; (*d=*s); s++, d++);
	return d0;
}
WEAK char *strncpy(char *d, const char *s, size_t n)
{
	char *d0=d;
	for (; n && (*d=*s); n--, s++, d++);
	return d0;
}
WEAK int strcmp(const char *l, const char *r)
{
	for (; *l==*r && *l; l++, r++);
	return *(unsigned char *)l - *(unsigned char *)r;
}
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

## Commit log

2025-08-30 Add schematic, update readme, and optimize code
    [CH32V003_SGM3732_Portable_LED.kicad_pcb, CH32V003_SGM3732_Portable_LED.kicad_sch]
2025-08-30 Update schematic
    [CH32V003_SGM3732_Portable_LED.kicad_pcb, CH32V003_SGM3732_Portable_LED.kicad_sch]
2025-08-30 Add sym-lib-table and block KiCad temporary files
2025-09-09 Add battery monitor and found the clock cannot be too low for ADC.
    [ch32fun.c, led.c]
2025-09-11 Add power monitor and OCD kicking in
2025-09-11 Move button functions to a new file and now support multiple buttons
2025-09-13 Add double press and fixed the power on transitional key release issue.
    [button.c, led.c]
2025-09-14 More improvements on button. - Support triple and more presses - Fix power on transitional problem, there will be no release event without a press, hold release is an exception.
    [button.c, led.c]
2025-09-14 Update readme and schematic
    [CH32V003_SGM3732_Portable_LED.kicad_sch]
2025-09-14 Update button names in schematic
    [CH32V003_SGM3732_Portable_LED.kicad_sch]
2025-09-30 60kHz PWM
2025-10-17 Change power LED wiring
2025-10-17 Add PCB
2025-10-26 Add gamma correction for breathing light mode
    [flashlight.c]

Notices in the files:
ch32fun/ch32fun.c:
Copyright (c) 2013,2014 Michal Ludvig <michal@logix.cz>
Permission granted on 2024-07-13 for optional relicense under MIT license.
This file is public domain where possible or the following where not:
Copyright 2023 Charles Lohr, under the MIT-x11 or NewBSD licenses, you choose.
